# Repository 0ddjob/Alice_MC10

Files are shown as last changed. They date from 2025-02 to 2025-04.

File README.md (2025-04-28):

# Purpose
Simple designs for the Tandy TRS-80 MC-10 and Matra Alice.

## [Internal 4KB-to-8KB RAM Upgrade](/Internal_8KB_RAM)
Upgrade the Alice or MC-10 internal RAM from 4KB to 8KB.  Note that the extra 4KB isn't available if the 16KB expansion is also attached.<br>

## [RGB Video Modification](/RGB_Video) (Work In Progress)
Convert the MC-10 video output from RF modulated to RGB - design is based on the Matra Alice.<br>

## [Expander](https://github.com/Fred72z/ALICE)
Check out [Fred72z's](https://github.com/Fred72z) excellent expansion for Alice & MC10 ... RAM, joysticks, cartridge.

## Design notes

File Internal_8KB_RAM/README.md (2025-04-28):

# Internal 4KB-to-8KB RAM Upgrade
## Background
This design is based on the work that Daniel Tufvesson documented on his [blog](https://www.waveguide.se/?article=expanding-the-trs-80-mc-10-internal-ram) for the Tandy TRS-80 MC-10. Please refer to his blog for the background and theory of the upgrade.<br>

Note that the additional 4KB is not usable with the 16KB RAM expansion as the expansion occupies the same space in memory.<br>

I have [tested Rev. A on my Alice](https://youtu.be/OvdkhOnV7no) but not yet (as of 27-Feb-2025) on my MC-10.<br>

## Why Do this?
The Alice/MC-10 shares its internal 4KB of RAM with the 6847 VDG.  The VDG can address up to 8KB of RAM but doesn't have access to the expansion bus, thus it can only access RAM that is installed internally.  The additional RAM allows access to additional video modes such as 128x192x4 and 256x192x2 graphics modes which require 6KB of RAM. <br>

Of course, software needs to be written to take advantage of this.<br>

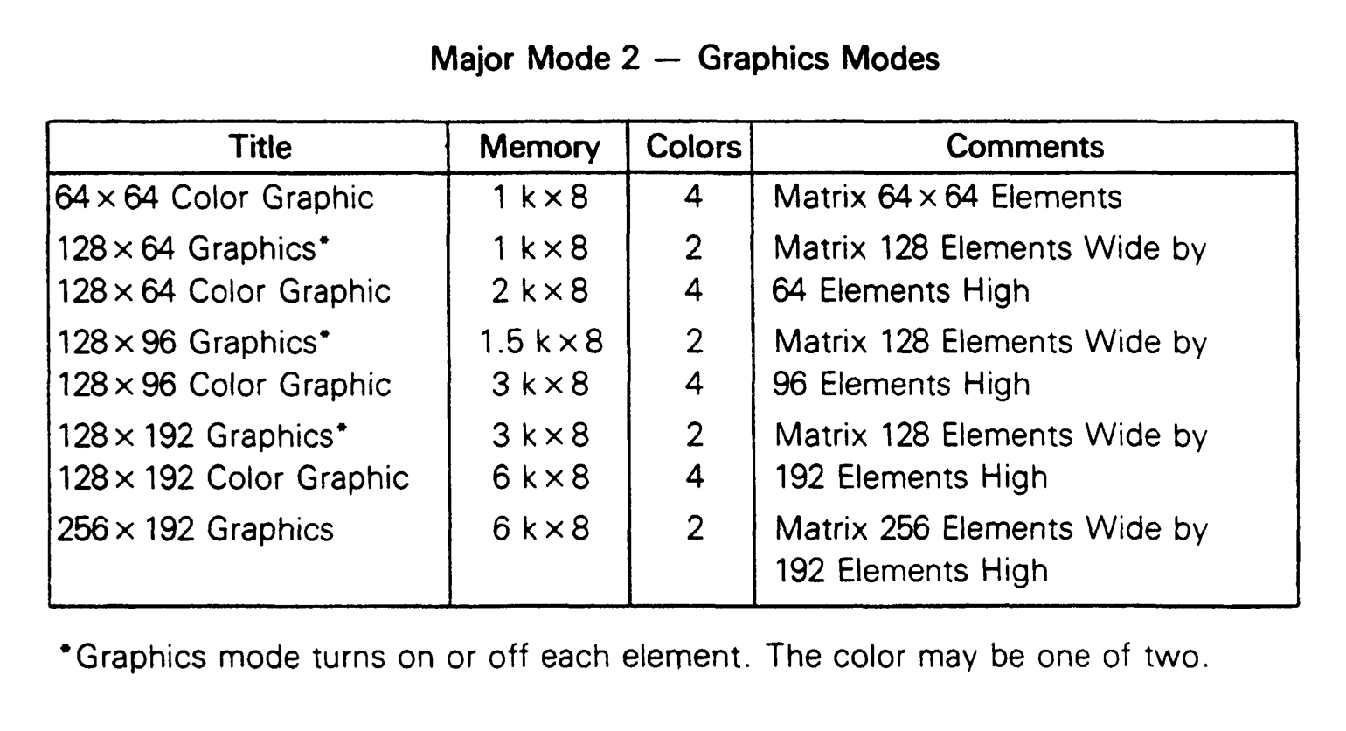
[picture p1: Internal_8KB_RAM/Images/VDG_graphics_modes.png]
6847 VDG Graphics Modes


## Free Memory
Standard Alice 4KB: 3142 bytes free<br>
Alice with 8KB: 7238 bytes free<br>
Standard Alice 4+16KB: 19526 bytes free<br>
Alice with 8+16KB: 19526 bytes free (additional 4KB overlapped)<br>

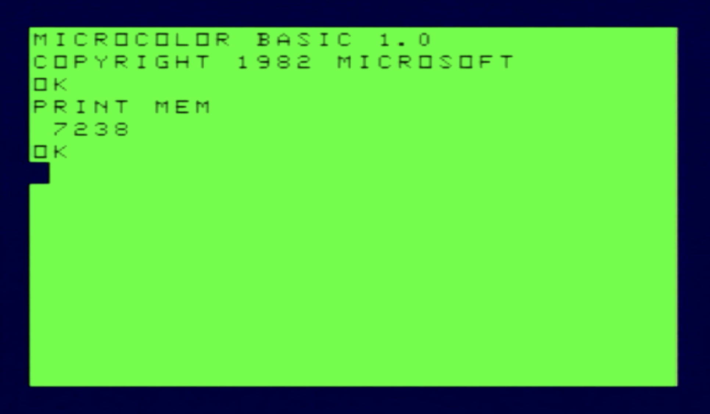
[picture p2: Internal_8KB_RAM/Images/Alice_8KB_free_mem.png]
Alice free memory with 8KB RAM


## Design
The MC-10 has a limitation with component height due to its rather [snug FCC shielding](https://www.waveguide.se/?article=getting-to-know-the-trs-80-mc-10) - the Matra Alice doesn't have this, hence this simple daughterboard design.  My MC-10 no longer has that limitation either!<br>

The Alice also doesn't have the bodge wiring for the 4KB address decoding that the MC-10 has.<br>

This is what the 8KB daughterboard looks like installed in the Alice:<br>

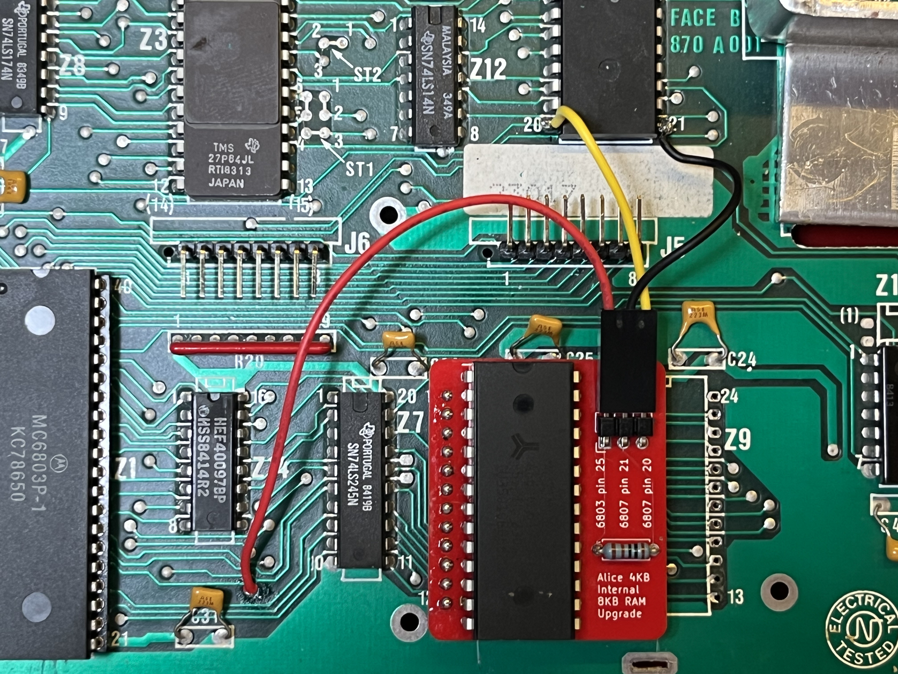
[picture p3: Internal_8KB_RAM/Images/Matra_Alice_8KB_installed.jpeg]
Internal daughterboard installed in Alice


(Sidenote 1: yes, the crossing of the black and yellow 6847 VDG address wires annoys me too - I have since updated the PCB so they don't cross!)<br>

(Sidenote 2: the original Thomson 6803 CPU in my Alice was faulty causing [keyboard issues](https://youtu.be/A9SVZOl3z24) - I replaced it with a socketed Motorola 6803 seen on the left).<br>

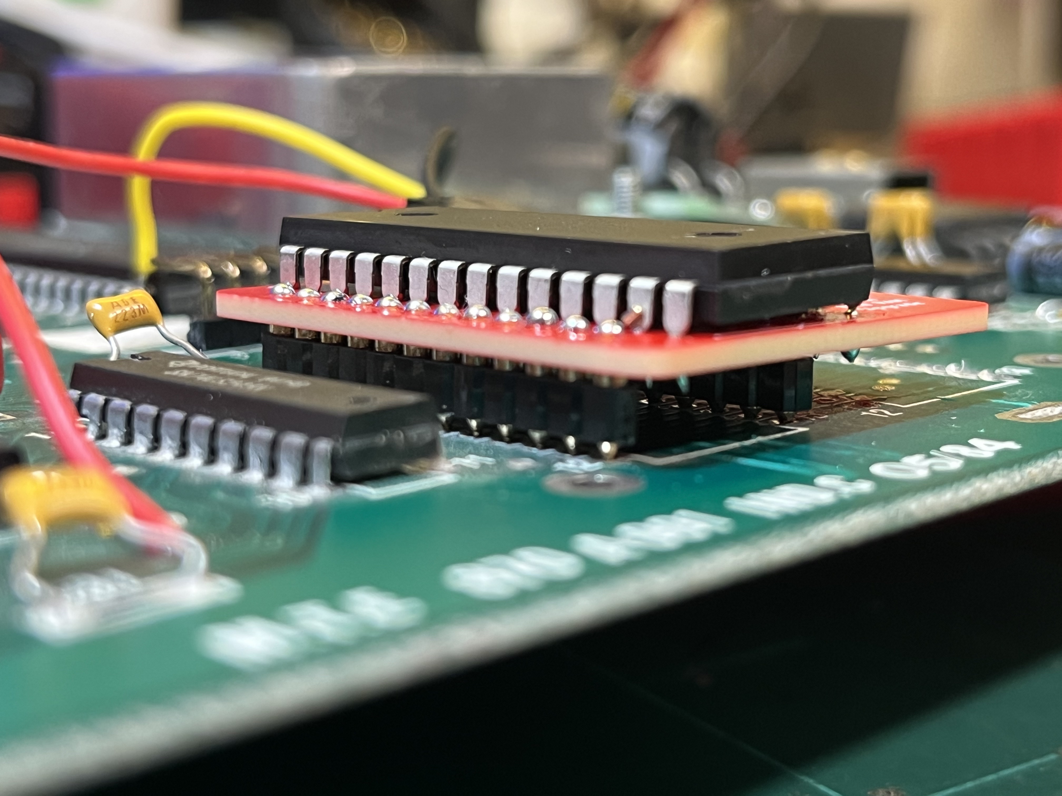
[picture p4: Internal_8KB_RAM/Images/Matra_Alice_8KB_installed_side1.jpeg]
Internal daughterboard installed in Alice sideview


On the MC-10 it is necessary to also move a bodge wire from A12 (6803 pin 25) to A13 (6803 pin 24).  On the Alice this simply requires cutting a track to pin 25 and connecting it to pin 24:<br>

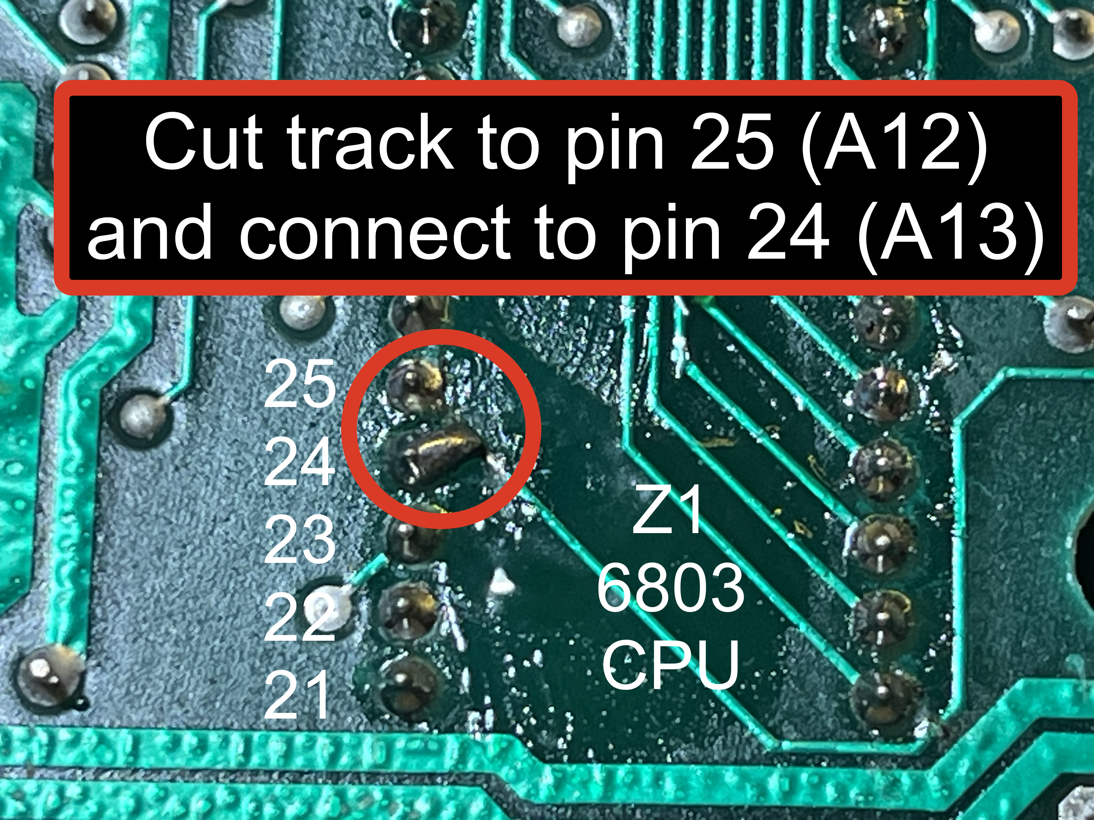
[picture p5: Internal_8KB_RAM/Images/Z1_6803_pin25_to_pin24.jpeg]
Alice bodge wire relocation


## Bill Of Materials
- PCB (thanks to [PCBWay](www.pcbway.com) for their ongoing sponsorship)
- 6264 static RAM (I didn't bother with a socket to keep height to a minimum)
- 1KΩ resistor
- 3-pin right-angle header & 3-way Dupont-type wire (or just wire directly)
- two 12-pin headers (or single row cut into 12-pins)

For the 12-pin headers I normally use "turned" pins in case I'm installing into an IC socket.  In this case I've just installed directly onto the board so the more common square-shaped header pins could be used instead.

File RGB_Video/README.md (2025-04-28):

# RGB Video Modification
## Background
This design is based on the Matra Alice schematic.  The Alice outputs an RGB+Audio signal via a 7-pin DIN socket - this would normally be connected to a Peritel or SCART connector.<br>

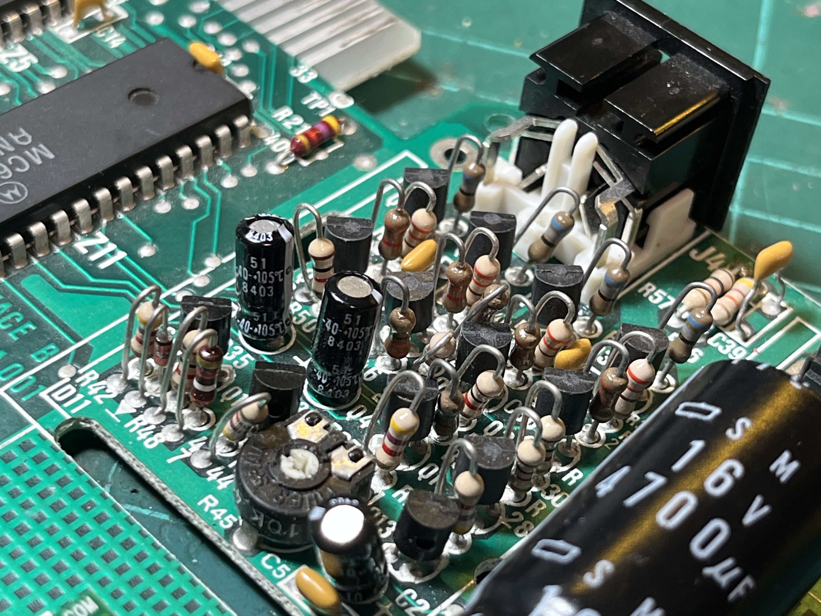
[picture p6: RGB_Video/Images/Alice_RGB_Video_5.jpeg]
Alice RGB Video Output Stage


## Design Notes
### Transistor Replacements
The original design uses obsolete transistors: BC172C (NPN) and BC252C (PNP).  I've tried to match with available transistors - not an expert, happy to be advised of better matches:<br>
BC172C -> BC550C<br>
BC252C -> BC559C<br>

### Video Pinout (7-pin DIN)
The video pinout is:<br>
- Pin 1 = Vcc (+12V) - only needed for SCART switching? 
- Pin 2 = ground
- Pin 3 = red
- Pin 4 = synch
- Pin 5 = green
- Pin 6 = audio
- Pin 7 = blue

The +12V connection to the DIN can be connected via solder bridge (default open).<br>

### Input Signals Required
- SYS_CLK_IN = U12 pin 12 (74LS14)
- SYS_CLK_OUT = U12 pin 13
- ΦA = U11 pin 11 (MC6847 VDG)
- ΦB = U11 pin 10 (MC6847 VDG)
- CHB = U11 pin 9 (MC6847 VDG)
- Y = U11 pin 28 (MC6847 VDG)

### Notable Differences Between Alice & MC-10
The crystal for the Alice is located next to the 6803 CPU whereas the MC-10's crystal is part of the RF modulator circuit, being generated by the MC1372.  This means that any modification to the MC-10's video output stage needs to include the crystal & system clock generation circuitry.<br>

At the moment I have the crystal & MC1372 being recovered and re-used.<br>

## Status
16-Mar-2025:<br>
Work in progress!<br>
The schematic is almost complete, verifying against the Alice schematic (a bit hard to see some parts) and an actual Alice.<br>
A PCB will then be designed and test PCBs fabricated.

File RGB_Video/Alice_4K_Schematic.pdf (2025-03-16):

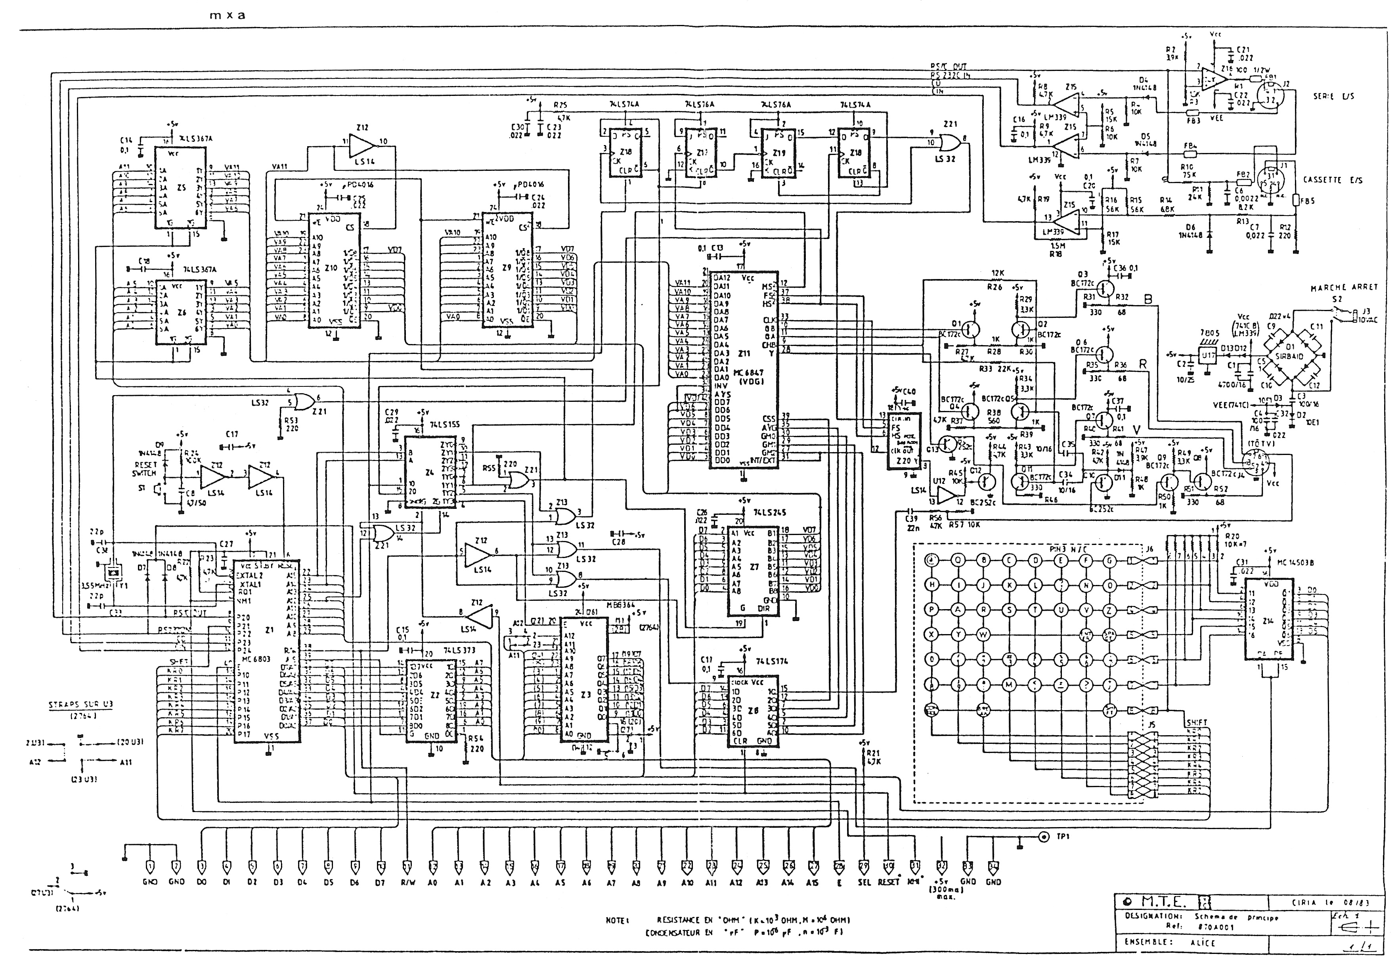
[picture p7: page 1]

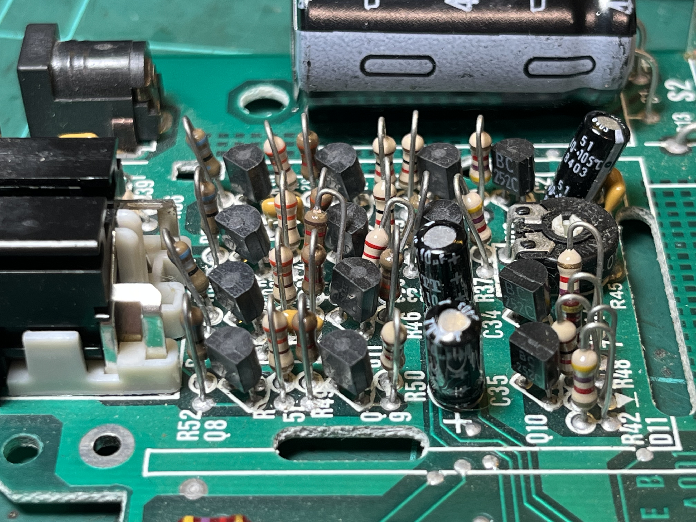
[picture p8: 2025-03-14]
RGB_Video/Images/Alice_RGB_Video_4.jpeg

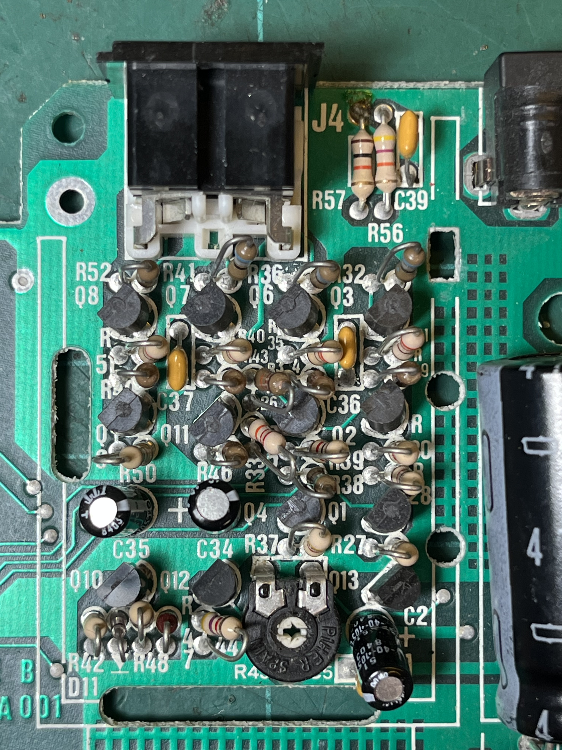
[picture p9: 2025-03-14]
RGB_Video/Images/Alice_RGB_Video_1.jpeg

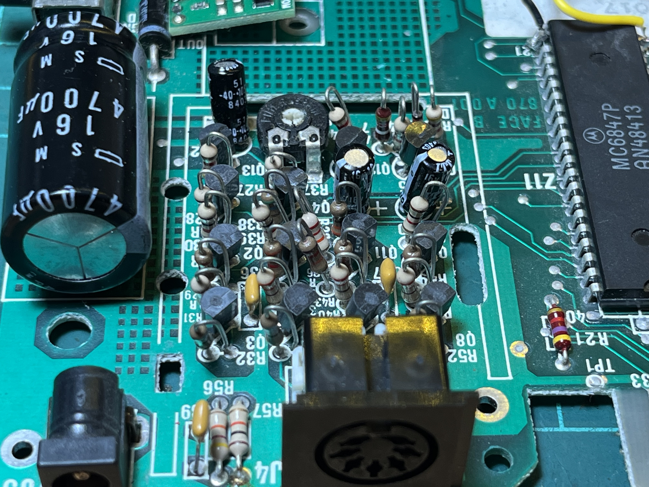
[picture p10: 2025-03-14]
RGB_Video/Images/Alice_RGB_Video_3.jpeg

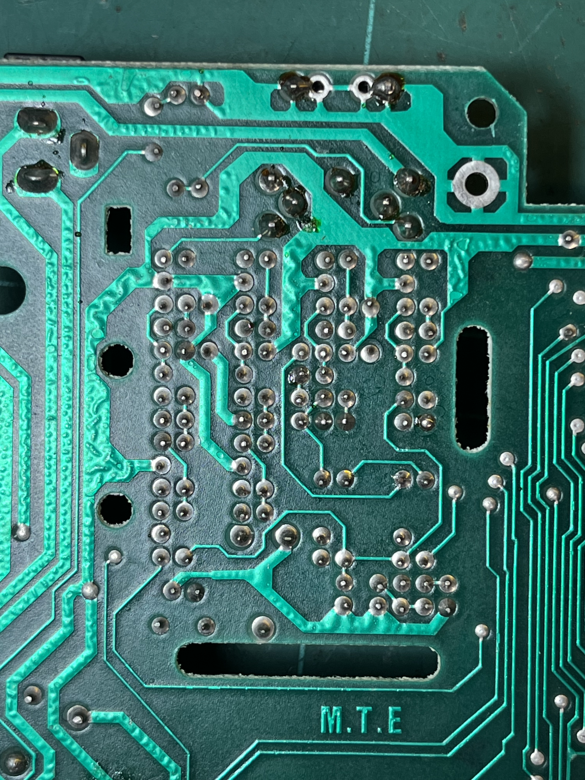
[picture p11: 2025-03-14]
RGB_Video/Images/Alice_RGB_Video_2.jpeg

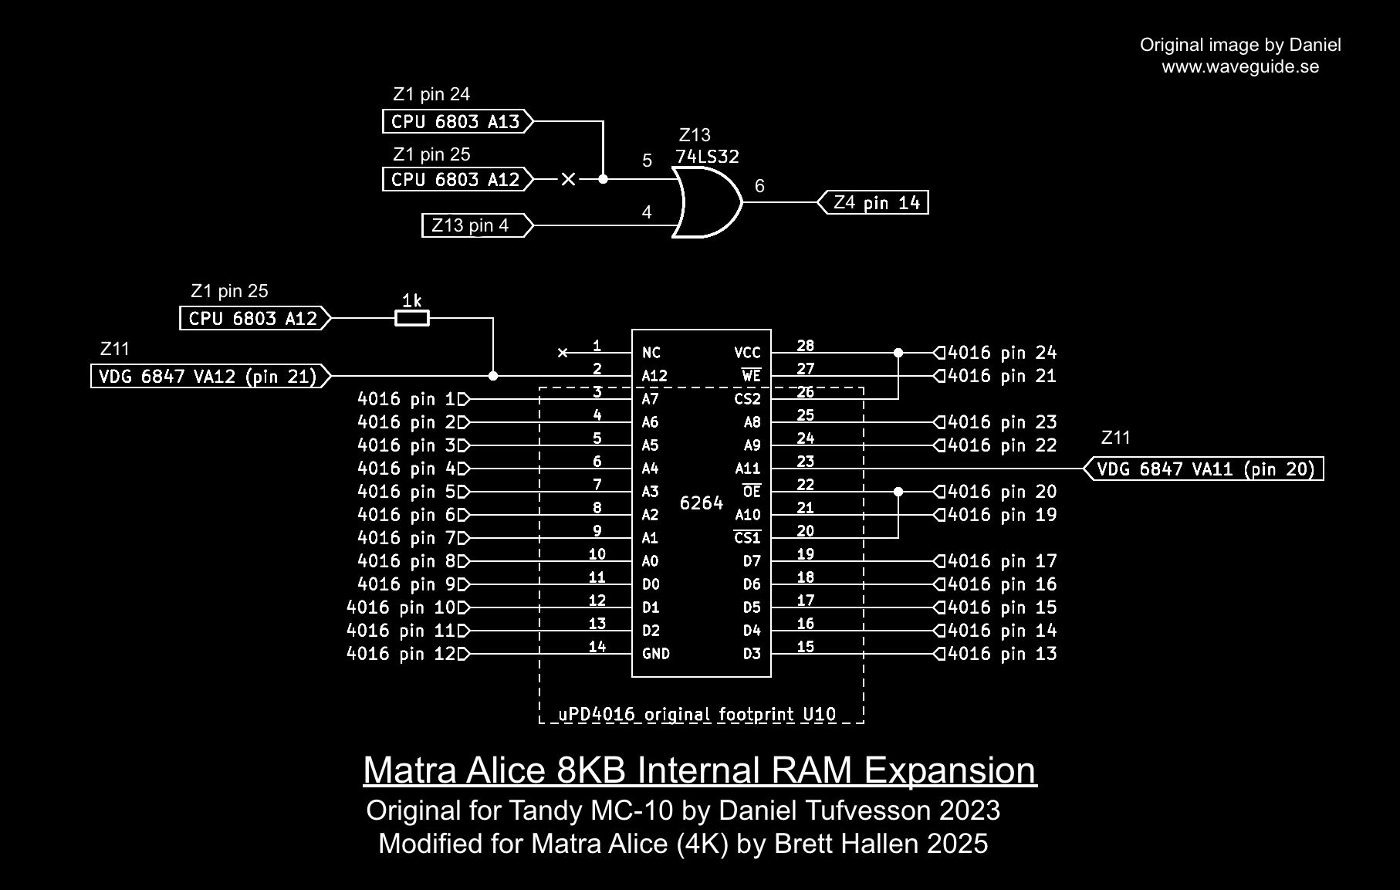
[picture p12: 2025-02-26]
Internal_8KB_RAM/Images/Matra_Alice_8k_expansion_sch.jpg

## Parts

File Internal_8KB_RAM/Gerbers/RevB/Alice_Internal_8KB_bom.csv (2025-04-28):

Designator | Quantity | Value | Footprint | Package | MPN | DNP | Mount_Type | Description
J1 | 1 | Conn_01x03 | PinHeader_1x03_P2.54mm_Horizontal |  |  |  | tht | Generic connector, single row, 01x03, script generated (kicad-library-utils/schlib/autogen/connector/)
R1 | 1 | 1KΩ | R_Axial_DIN0207_L6.3mm_D2.5mm_P7.62mm_Horizontal |  |  |  | tht | Resistor
U1 | 1 | 6264 | DIP-28_W15.24mm |  |  |  | tht
Z10 | 1 | D4016 | DIP-24_W15.24mm |  |  |  | tht

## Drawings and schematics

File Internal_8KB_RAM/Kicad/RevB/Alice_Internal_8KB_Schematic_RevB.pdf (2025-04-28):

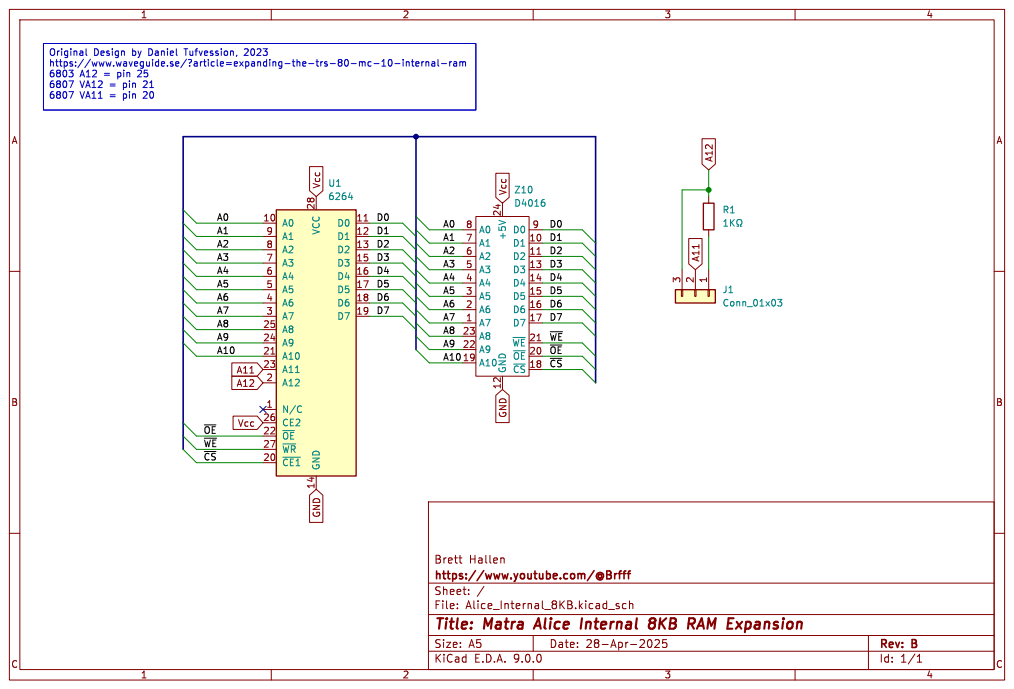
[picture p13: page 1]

https://www.waveguide.se/?article=expanding-the-trs-80-mc-10-internal-ram
6803 A12 = pin 25
6807 VA12 = pin 21
6807 VA11 = pin 20

https://www.youtube.com/@Brfff
Sheet: /
File: Alice_Internal_8KB.kicad_sch
Title: Matra Alice Internal 8KB RAM Expansion

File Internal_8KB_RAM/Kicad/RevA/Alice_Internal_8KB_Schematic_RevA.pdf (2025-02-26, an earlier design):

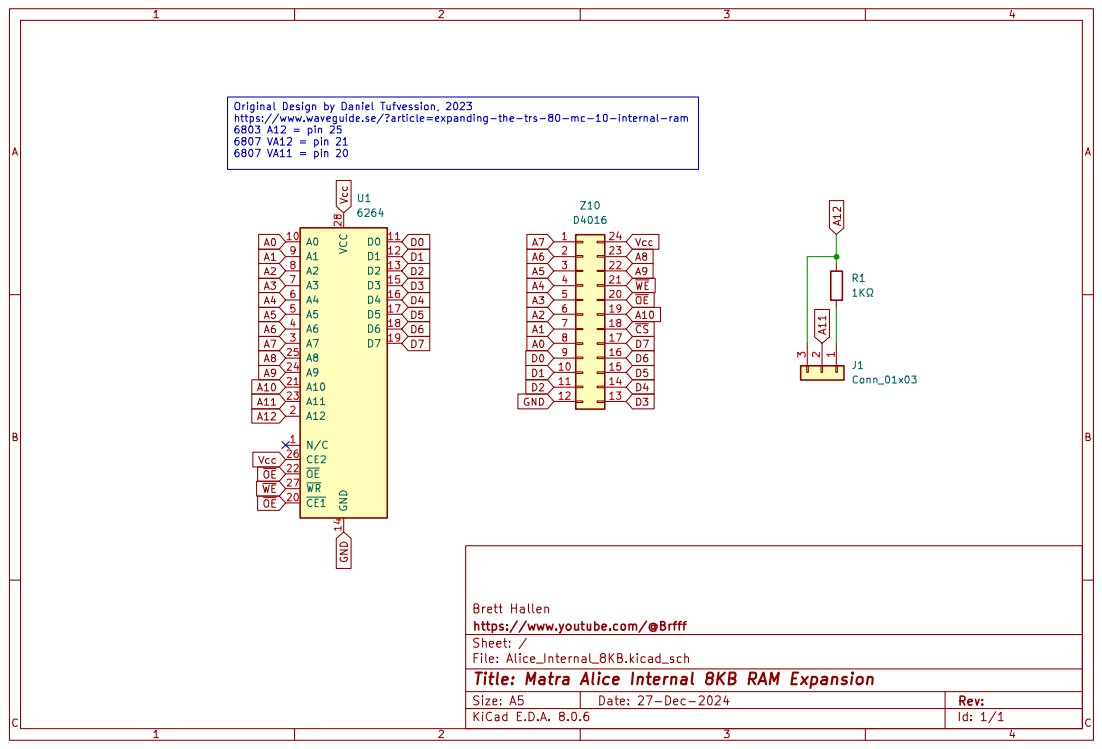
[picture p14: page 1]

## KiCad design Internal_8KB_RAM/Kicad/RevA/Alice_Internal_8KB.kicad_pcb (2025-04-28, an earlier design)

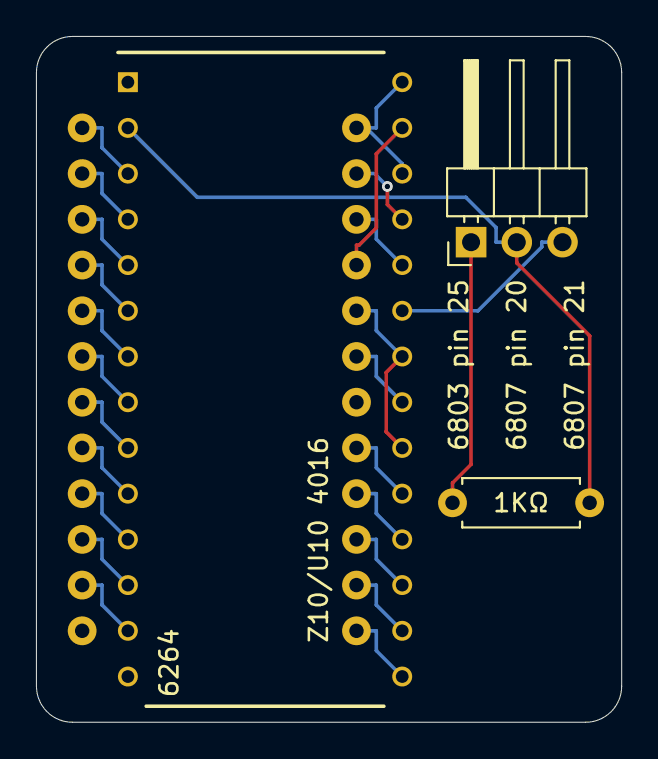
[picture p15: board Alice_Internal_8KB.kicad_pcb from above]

Board: 2 copper layers, 32.5 x 38.1 mm, 4 parts (0 on the bottom side), 26 nets.

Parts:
J1: Conn_01x03; PinHeader_1x03_P2.54mm_Horizontal
R1: 1KΩ; R_Axial_DIN0207_L6.3mm_D2.5mm_P7.62mm_Horizontal
U1: 6264; DIP1524W51P254L3632H394Q28N
Z10: D4016; DIP-24_W15.24mm-Notch

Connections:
A0: U1.10 (A0), Z10.8
A1: U1.9 (A1), Z10.7
A2: U1.8 (A2), Z10.6
A3: U1.7 (A3), Z10.5
A4: U1.6 (A4), Z10.4
A5: U1.5 (A5), Z10.3
A6: U1.4 (A6), Z10.2
A7: U1.3 (A7), Z10.1
A8: U1.25 (A8), Z10.23
A9: U1.24 (A9), Z10.22
A10: U1.21 (A10), Z10.19
A11: J1.3 (6847_p20), U1.23 (A11)
A12: J1.2 (6847_p21), R1.1, U1.2 (A12)
D0: U1.11 (D0), Z10.9
D1: U1.12 (D1), Z10.10
D2: U1.13 (D2), Z10.11
D3: U1.15 (D3), Z10.13
D4: U1.16 (D4), Z10.14
D5: U1.17 (D5), Z10.15
D6: U1.18 (D6), Z10.16
D7: U1.19 (D7), Z10.17
GND: U1.14 (GND), Z10.12
unnamed: J1.1 (6803_p25), R1.2
Vcc: U1.26 (CE2), U1.28 (VCC), Z10.24
~OE: U1.20 (~CE1), U1.22 (~OE), Z10.20
~WE: U1.27 (~WR), Z10.21

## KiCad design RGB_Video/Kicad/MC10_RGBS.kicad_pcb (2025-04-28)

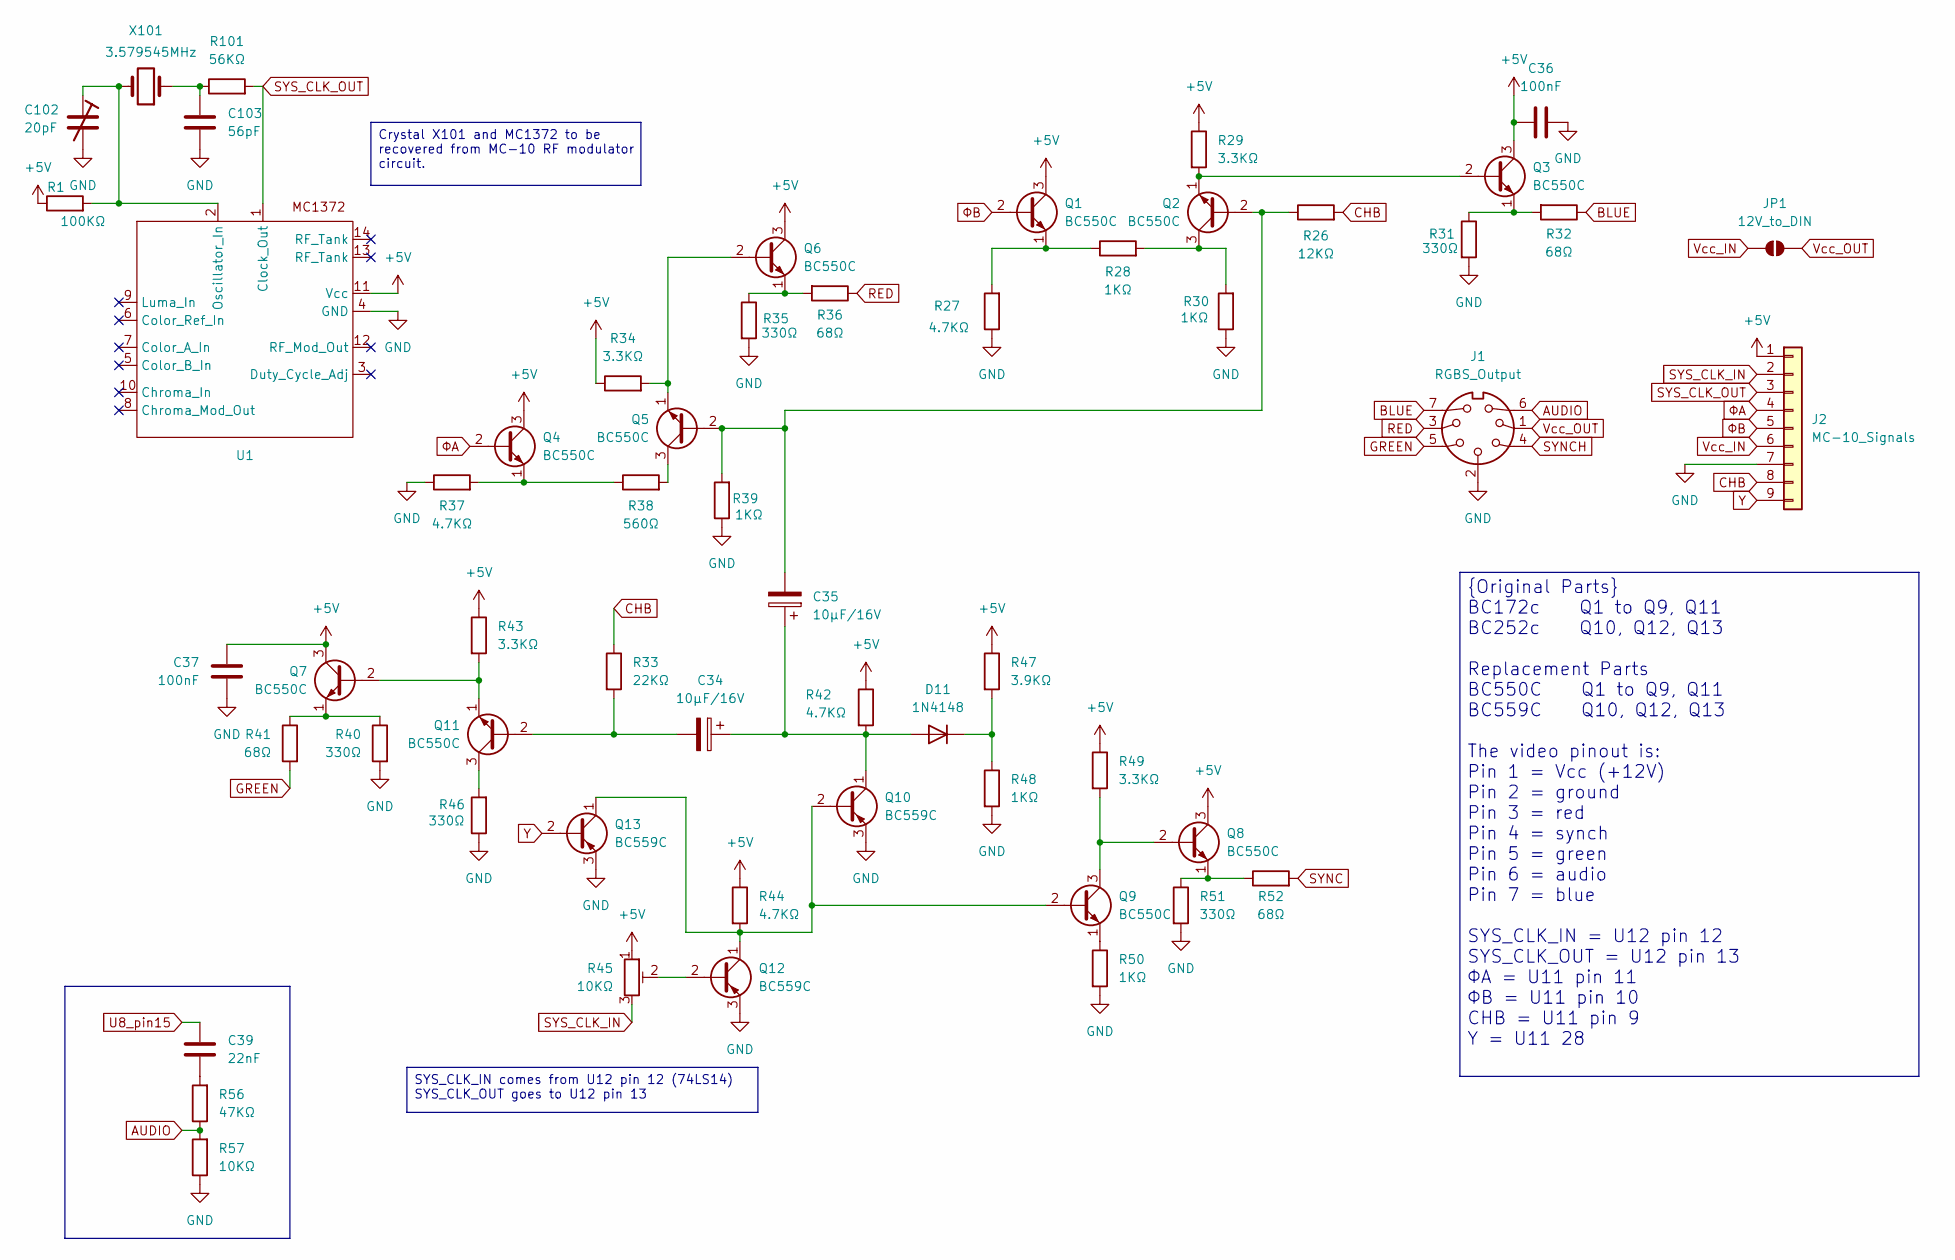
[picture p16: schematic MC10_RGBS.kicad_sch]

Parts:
C34, C35: 10µF/16V; CP_Radial_D5.0mm_P2.50mm
C36, C37: 100nF; C_Disc_D3.0mm_W2.0mm_P2.50mm
C39: 22nF; C_Disc_D3.0mm_W2.0mm_P2.50mm
C102: 20pF; C_Trimmer_Murata_TZB4-B
C103: 56pF; C_Disc_D3.0mm_W2.0mm_P2.50mm
D11: 1N4148; D_SOD-323_HandSoldering
J1: RGBS_Output; PinHeader_1x07_P2.54mm_Vertical
J2: MC-10_Signals; PinSocket_1x09_P2.54mm_Vertical
JP1: 12V_to_DIN; SolderJumper-2_P1.3mm_Open_Pad1.0x1.5mm
Q1, Q2, Q3, Q4, Q5, Q6, Q7, Q8, Q9, Q11: BC550C; TO-92_Inline
Q10, Q12, Q13: BC559C; TO-92_Inline
R1: 100KΩ; R_0603_1608Metric_Pad0.98x0.95mm_HandSolder
R26: 12KΩ; R_0603_1608Metric_Pad0.98x0.95mm_HandSolder
R27, R37, R42, R44: 4.7KΩ; R_0603_1608Metric_Pad0.98x0.95mm_HandSolder
R28, R30, R39, R48, R50: 1KΩ; R_0603_1608Metric_Pad0.98x0.95mm_HandSolder
R29, R34, R43, R49: 3.3KΩ; R_0603_1608Metric_Pad0.98x0.95mm_HandSolder
R31, R35, R40, R46, R51: 330Ω; R_0603_1608Metric_Pad0.98x0.95mm_HandSolder
R32, R36, R41, R52: 68Ω; R_0603_1608Metric_Pad0.98x0.95mm_HandSolder
R33: 22KΩ; R_0603_1608Metric_Pad0.98x0.95mm_HandSolder
R38: 560Ω; R_0603_1608Metric_Pad0.98x0.95mm_HandSolder
R45: 10KΩ; PTN091V10115K1B
R47: 3.9KΩ; R_0603_1608Metric_Pad0.98x0.95mm_HandSolder
R56: 47KΩ; R_0603_1608Metric_Pad0.98x0.95mm_HandSolder
R57: 10KΩ; R_0603_1608Metric_Pad0.98x0.95mm_HandSolder
R101: 56KΩ; R_0603_1608Metric_Pad0.98x0.95mm_HandSolder
U1: DIP-14_W7.62mm
X101: 3.579545MHz; Crystal_HC49-U_Vertical

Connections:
+5V: C36.1, C37.1, J2.1, Q1.3 (C), Q3.3 (C), Q4.3 (C), Q6.3 (C), Q7.3 (C), Q8.3 (C), R1.1, R29.1, R34.1, R42.1, R43.1, R44.1, R45.1, R47.1, R49.1, U1.11 (Vcc)
AUDIO: J1.6, R56.1, R57.2
BLUE: J1.7, R32.1
CHB: J2.8, R26.2, R33.1
GND: C36.2, C37.2, C102.2, C103.2, J1.2, J2.7, Q10.3 (E), Q12.3 (E), Q13.3 (E), R27.1, R30.1, R31.2, R35.2, R37.1, R39.1, R40.2, R46.1, R48.2, R50.2, R51.2, R57.1, U1.4 (GND)
GREEN: J1.5, R41.2
unnamed: C39.1, R56.2
unnamed: C103.1, R101.1, X101.1
unnamed: C34.1, C35.1, D11.2 (A), Q10.1 (C), R42.2
unnamed: D11.1 (K), R47.2, R48.1
unnamed: Q1.1 (E), R27.2, R28.1
unnamed: C35.2, Q2.2 (B), Q5.2 (B), R26.1, R39.2
unnamed: Q2.3 (C), R28.2, R30.2
unnamed: Q2.1 (E), Q3.2 (B), R29.2
unnamed: Q3.1 (E), R31.1, R32.2
unnamed: Q4.1 (E), R37.2, R38.1
unnamed: Q5.3 (C), R38.2
unnamed: Q5.1 (E), Q6.2 (B), R34.2
unnamed: Q6.1 (E), R35.1, R36.2
unnamed: Q7.1 (E), R40.1, R41.1
unnamed: Q8.2 (B), Q9.3 (C), R49.2
unnamed: Q8.1 (E), R51.1, R52.1
unnamed: Q9.1 (E), R50.1
unnamed: Q9.2 (B), Q10.2 (B), Q12.1 (C), Q13.1 (C), R44.2
unnamed: C34.2, Q11.2 (B), R33.2
unnamed: Q11.3 (C), R46.2
unnamed: Q7.2 (B), Q11.1 (E), R43.2
unnamed: Q12.2 (B), R45.2
unnamed: C102.1, R1.2, U1.2 (Oscillator_In), X101.2
RED: J1.3, R36.1
SYNC: R52.2
SYNCH: J1.4
SYS_CLK_IN: J2.2, R45.3
SYS_CLK_OUT: J2.3, R101.2, U1.1 (Clock_Out)
U8_pin15: C39.2
Vcc_IN: J2.6, JP1.1 (A)
Vcc_OUT: J1.1, JP1.2 (B)
Y: J2.9, Q13.2 (B)
ΦA: J2.4, Q4.2 (B)
ΦB: J2.5, Q1.2 (B)

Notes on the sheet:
{Original Parts} BC172c Q1 to Q9, Q11 BC252c Q10, Q12, Q13 Replacement Parts BC550C Q1 to Q9, Q11 BC559C Q10, Q12, Q13 The video pinout is: Pin 1 = Vcc (+12V) Pin 2 = ground Pin 3 = red Pin 4 = synch Pin 5 = green Pin 6 = audio Pin 7 = blue SYS_CLK_IN = U12 pin 12 SYS_CLK_OUT = U12 pin 13 ΦA = U11 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
SYS_CLK_IN comes from U12 pin 12 (74LS14) SYS_CLK_OUT goes to U12 pin 13
Crystal X101 and MC1372 to be recovered from MC-10 RF modulator circuit.

Board: 2 copper layers, 57 parts (0 on the bottom side), 37 nets, no tracks yet.

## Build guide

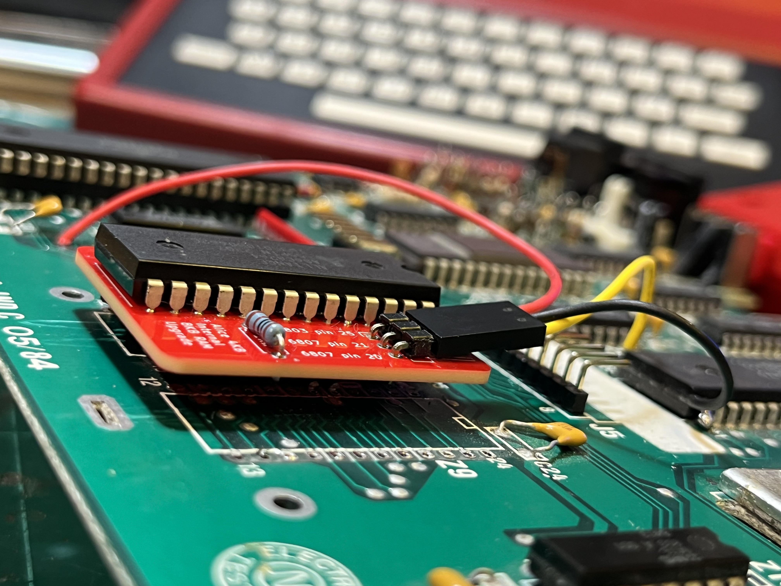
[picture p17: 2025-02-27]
Internal_8KB_RAM/Images/Matra_Alice_8KB_installed_side2.jpeg

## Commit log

2025-02-26 Add schematic & VDG mode info
2025-02-27 Rearrange files
    [Alice_Internal_8KB.kicad_pcb, Alice_Internal_8KB.kicad_sch]
2025-03-14 Added RGB video section
    [MC10_RGBS.kicad_pcb, MC10_RGBS.kicad_sch]
2025-03-14 Renamed schematic
2025-03-14 Added images of Alice RGB output stage
2025-03-16 Added MC1372 for system clock generation
    [MC10_RGBS.kicad_sch]
2025-04-28 Changed transistor types
    [MC10_RGBS.kicad_pcb, MC10_RGBS.kicad_sch]
2025-04-28 Updated design with Rev. B
    [Alice_Internal_8KB.kicad_pcb, Alice_Internal_8KB.kicad_sch, Alice_Internal_8KB_bom.csv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]
